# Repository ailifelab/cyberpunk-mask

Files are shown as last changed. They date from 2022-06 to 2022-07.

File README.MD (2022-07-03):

# Cyberpunk Mask    
一个基于ESP32的赛博朋克面具，通过右上角的菜单和按钮选择左下角屏幕显示的动画，以及控制跑马灯的灯效。

<hr>        

## 文件说明        
- CyberpunkMaskEsp32    
  基于Arduino的ESP-WAROOM-32代码，Boards Manager请安装esp32插件。

- MaskParts     
  solidworks模型文件
  - stl     
    STL格式的模型文件
<hr>

## 开发环境        
- Arduino IDE [1.8.19]      
- Board: esp32 [2.0.2]
  - DOIT ESP32 DEVKIT V1    
  - Upload speed: 921600 (Default)
  - Flash frequency: 80MHz (Default)
- Libraries:        
  - ESP32 Digital RGB LED Drivers [76863da42599f7b082821e4cee0ea00ba23b0918] | https://github.com/MartyMacGyver/ESP32-Digital-RGB-LED-Drivers | WS2812跑马灯带 (安装库的非本次使用的版本，已复制到本项目代码中)      
  - ESP8266 and ESP32 OLED driver for SSD1306 displays [4.3.0]| https://github.com/ThingPulse/esp8266-oled-ssd1306 | SSD1306 OLED I2C屏幕       
  - Time [1.6.1] | Arduino 时间库      
 
<hr>

## 电路图
本次使用的是Goouuu-ESP32，引脚定义如下，可以根据实际芯片的端口调整接线，具体请调整代码中的I/O定义。      
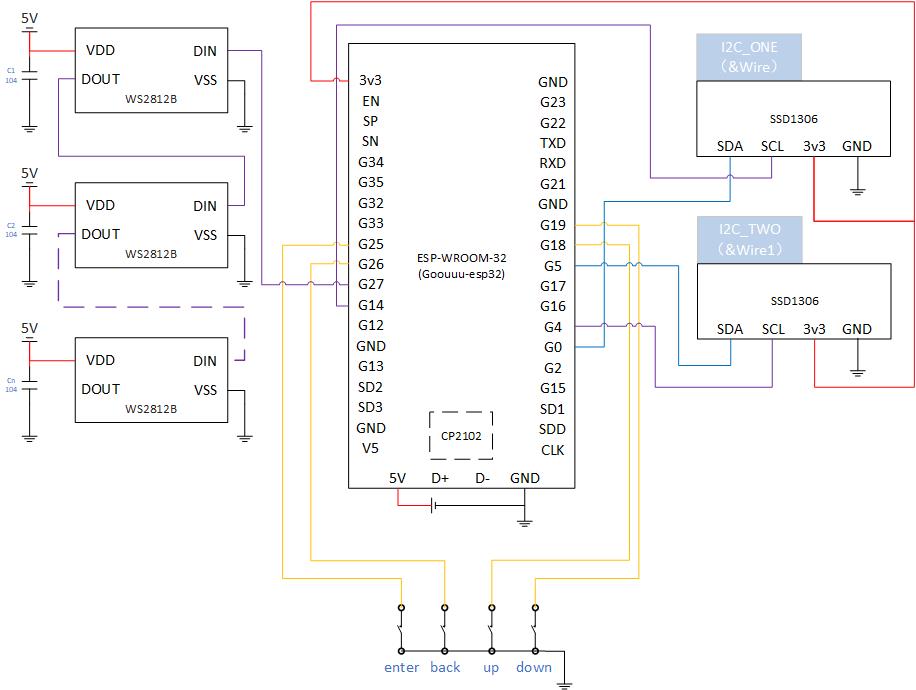
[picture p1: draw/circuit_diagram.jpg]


## 装配
### 3D打印的零件(TPU打印材料 ￥64/kg)        
- 菜单显示屏固定架(part_menu_frame)：      
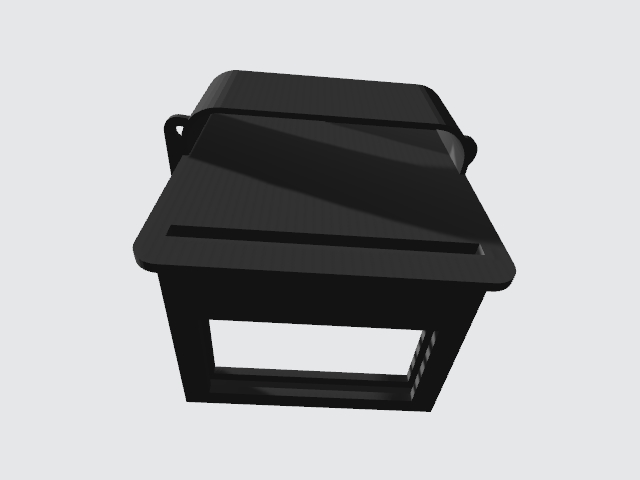
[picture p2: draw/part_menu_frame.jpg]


- 图形显示屏固定架(part_screen_frame)：      
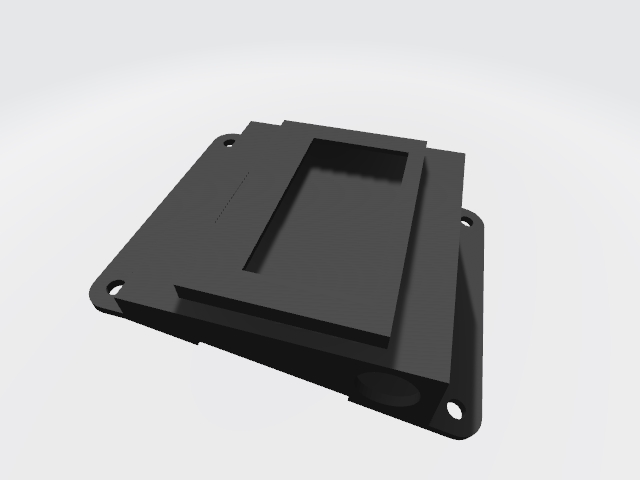
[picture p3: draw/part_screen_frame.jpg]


- 中间连接器(part_connector)：      
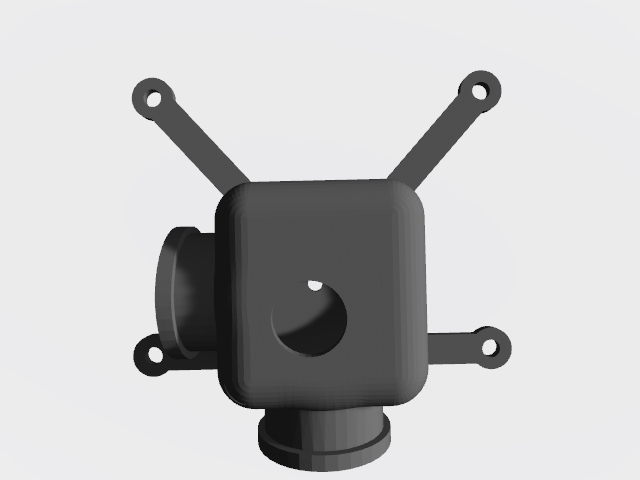
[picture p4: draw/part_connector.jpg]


- 主板固定架(part_board_cage)：      
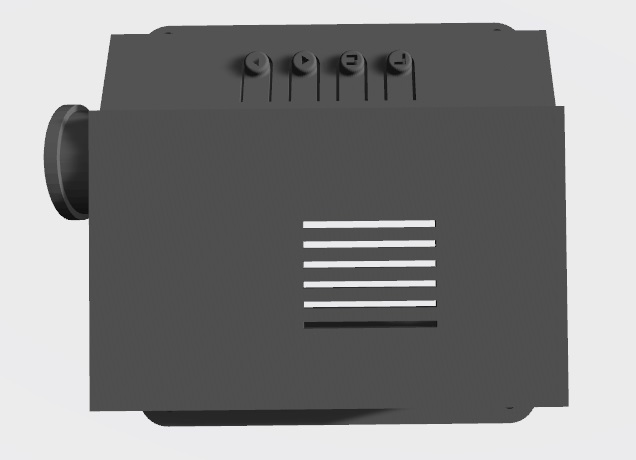
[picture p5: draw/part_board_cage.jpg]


### 购买的零件
- 面具（￥25）      
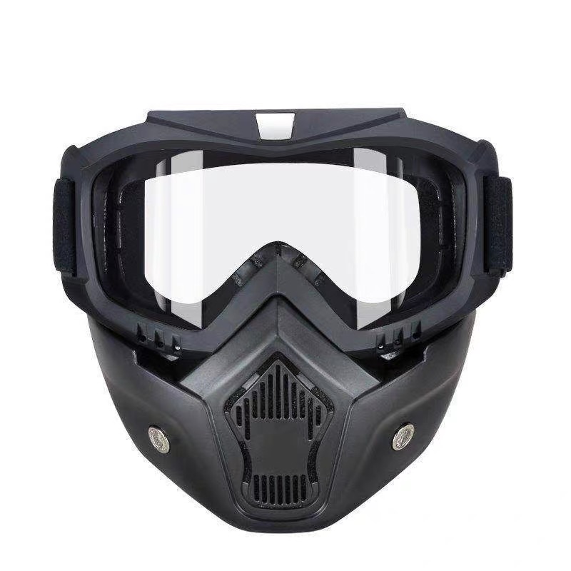
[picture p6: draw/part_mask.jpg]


- OLED透明显示屏1.51寸 128*64（SSD1306 ￥56）×2       
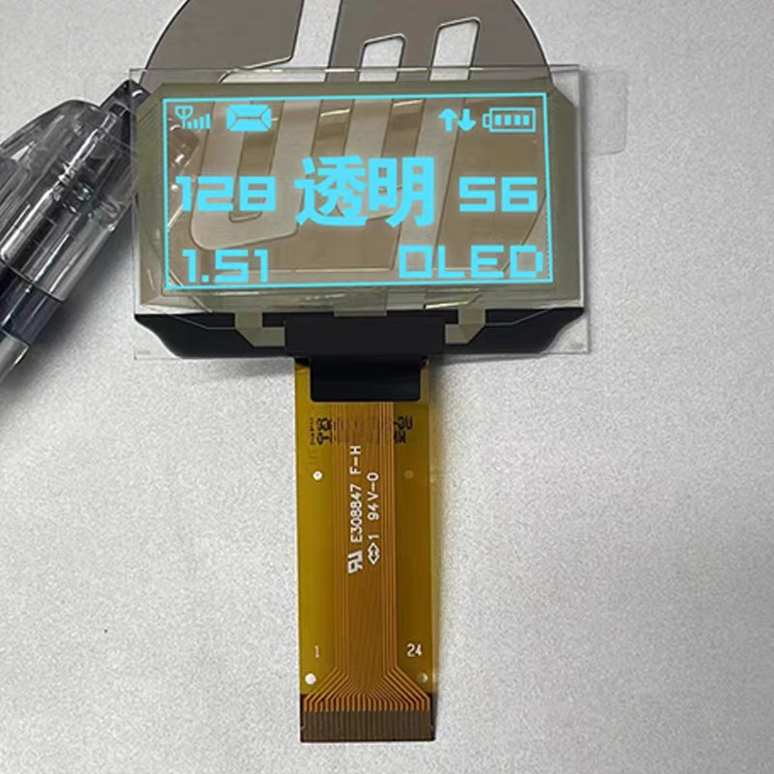
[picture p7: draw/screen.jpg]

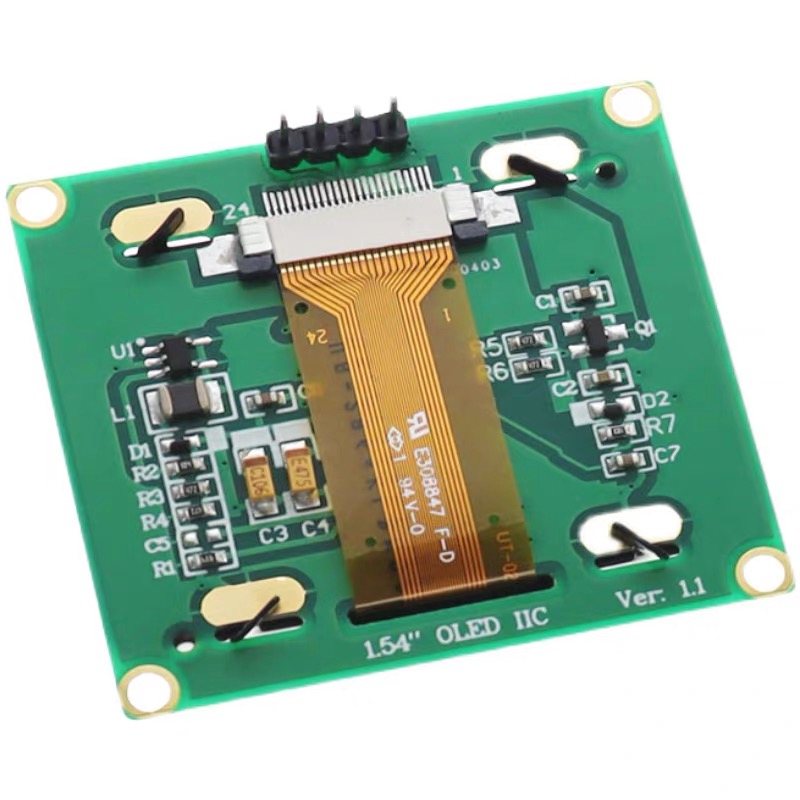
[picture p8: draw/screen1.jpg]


- WS2812B LED灯带 60灯（￥17/m）        
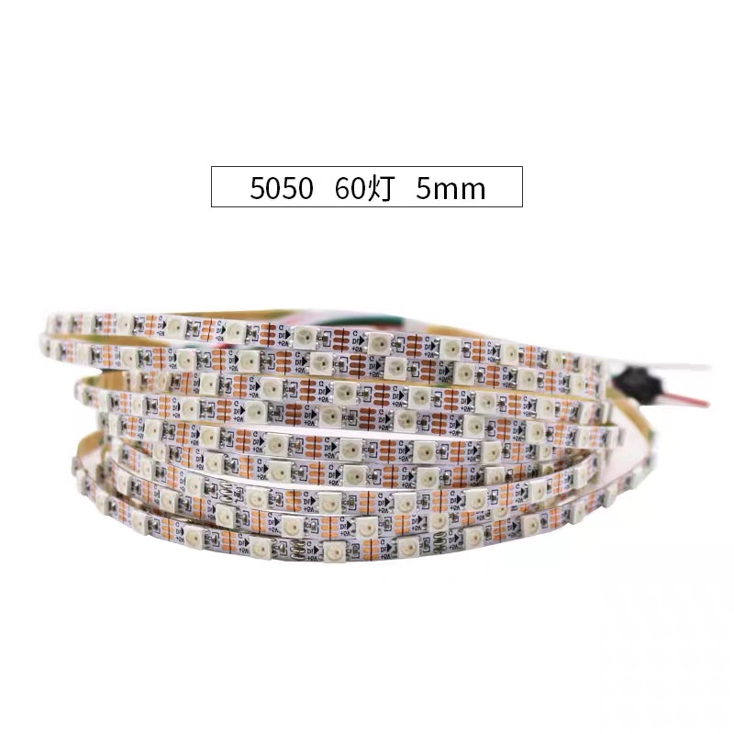
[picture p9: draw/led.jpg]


- ESP32 ESP-WROOM-32（Goouuu-ESP32 ￥21）     
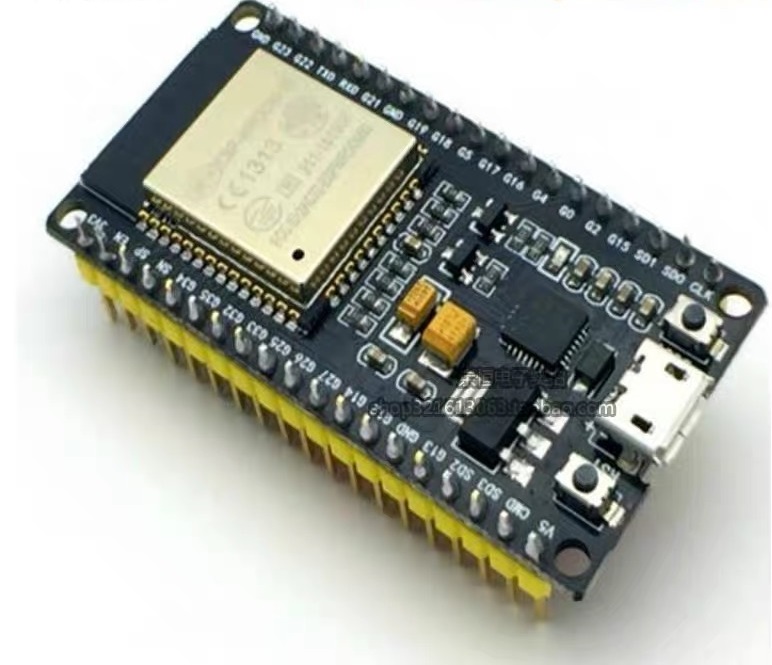
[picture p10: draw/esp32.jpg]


- PE波纹管（AD10:￥5/5m,AD21.2：￥5.8/5m）     
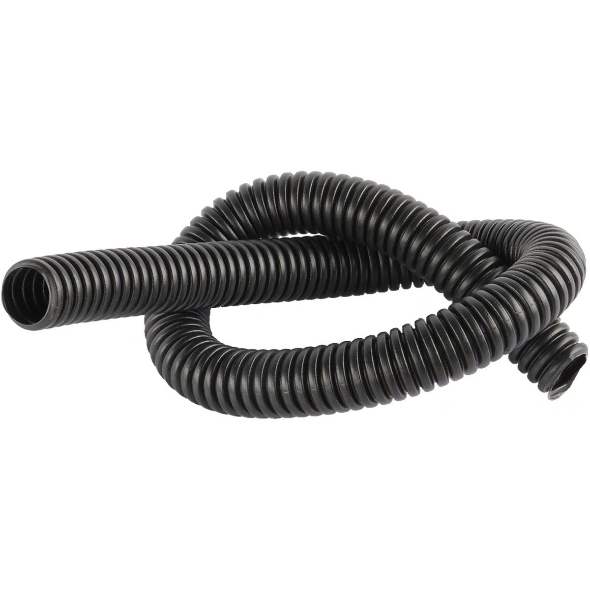
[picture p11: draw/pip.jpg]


- 灯带硅胶外壳（D13*13 ￥10/m）          
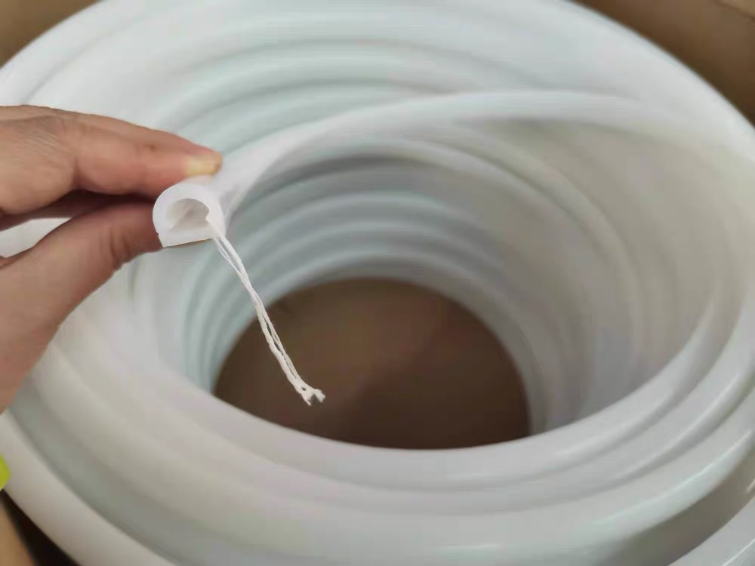
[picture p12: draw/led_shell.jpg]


- 导线若干

### 成品      
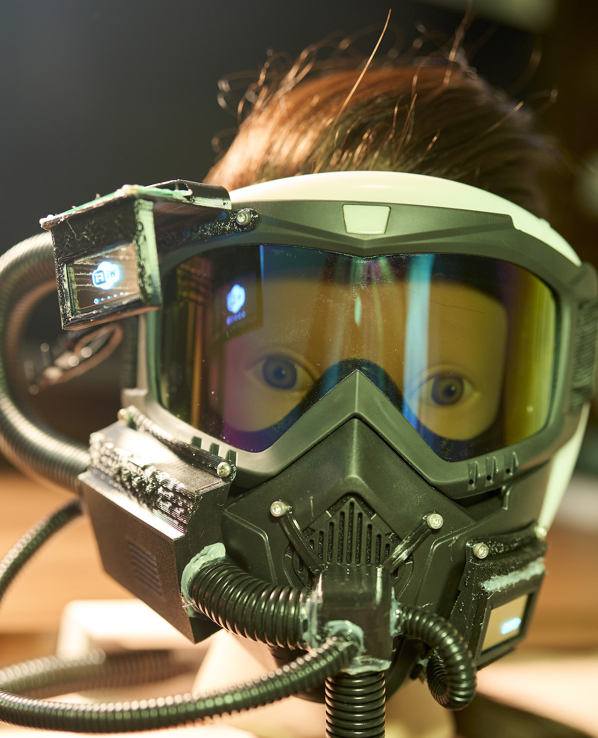
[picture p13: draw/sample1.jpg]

<hr>

## 效果
Play on youtube (https://www.youtube.com/embed/BOateCBAd_g)

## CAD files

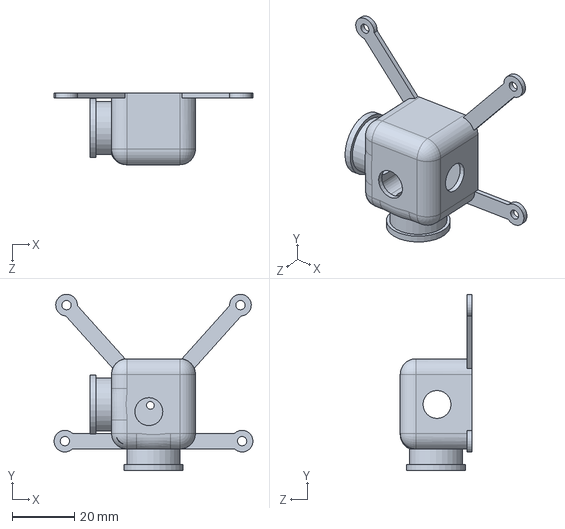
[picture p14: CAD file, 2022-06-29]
MaskParts/part_connector.SLDPRT
64.0 x 56.7 x 23.0 mm

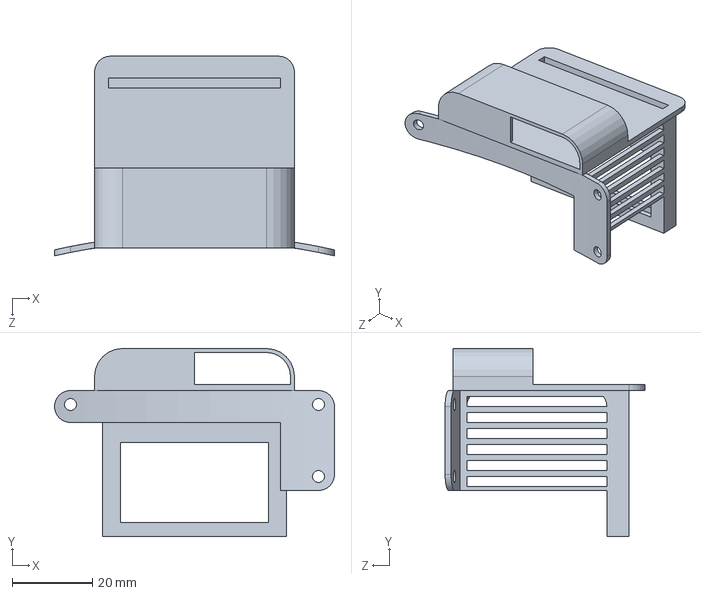
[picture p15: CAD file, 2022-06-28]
MaskParts/part_menu_frame.SLDPRT
70.0 x 47.0 x 49.9 mm

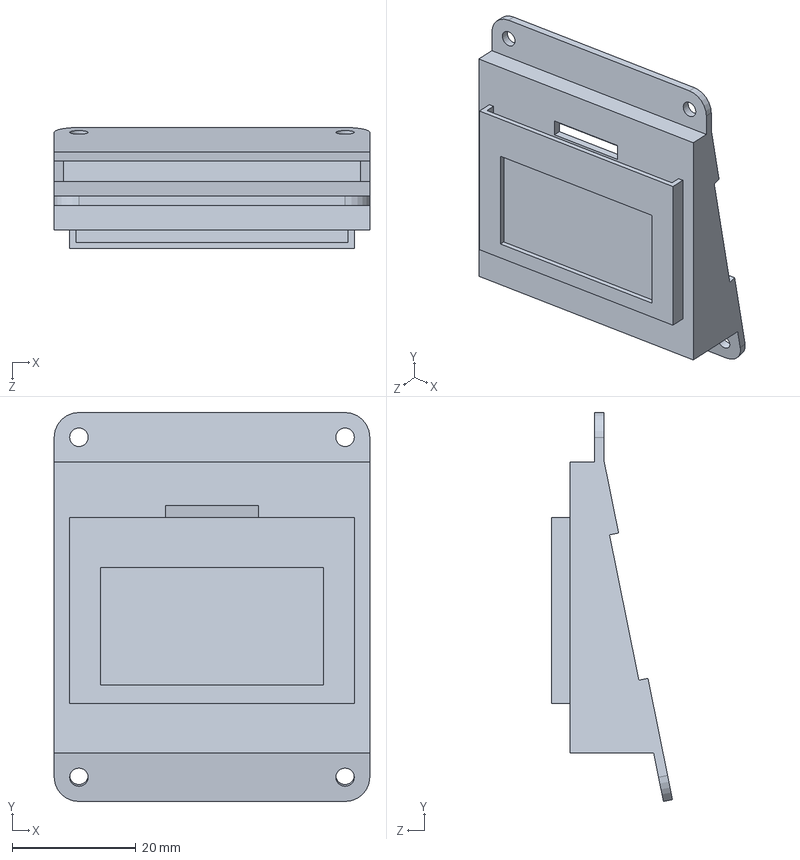
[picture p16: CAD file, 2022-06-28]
MaskParts/part_screen_frame.SLDPRT
51.0 x 62.8 x 19.6 mm

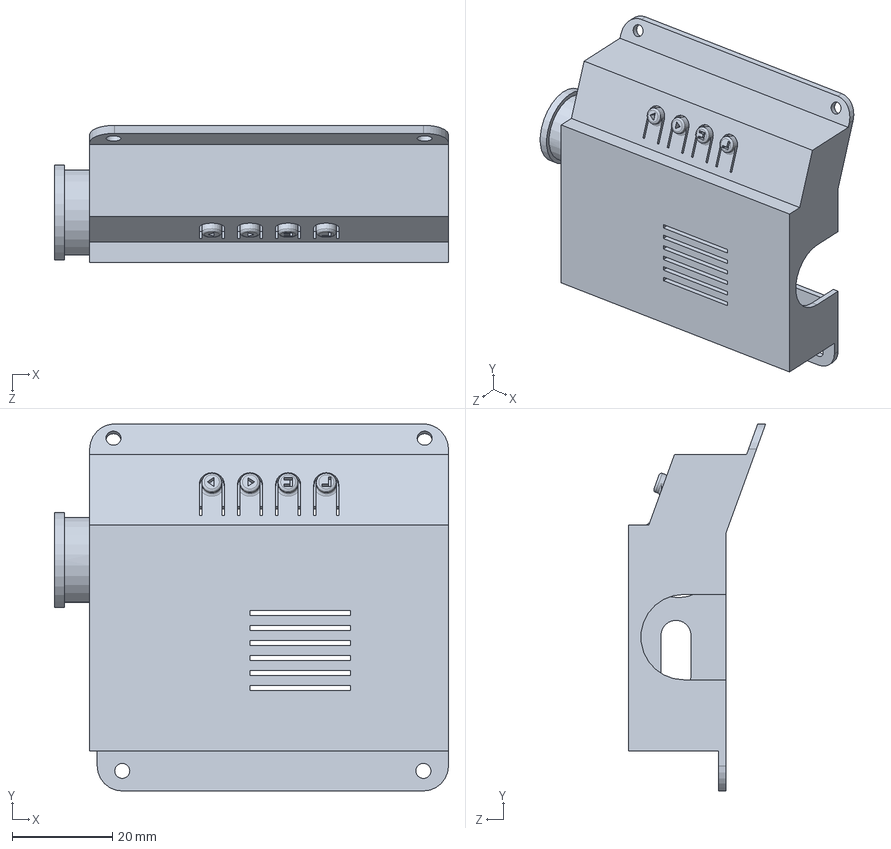
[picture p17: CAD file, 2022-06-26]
MaskParts/part_board_cage.SLDPRT
78.5 x 73.1 x 27.4 mm

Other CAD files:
MaskParts/stl/part_board_cage.STL
MaskParts/stl/part_connector.STL
MaskParts/stl/part_menu_frame.STL
MaskParts/stl/part_screen_frame.STL

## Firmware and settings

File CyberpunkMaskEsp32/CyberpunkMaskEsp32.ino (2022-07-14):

/**
   Cyberpunk Mask Diplay Controller
   使用ESP-WROOM-32主板
   External libraries:
     1.ESP32 Digital RGB LED Drivers | https://github.com/MartyMacGyver/ESP32-Digital-RGB-LED-Drivers | WS2812跑马灯带
     2.ESP8266 and ESP32 OLED driver for SSD1306 displays| https://github.com/ThingPulse/esp8266-oled-ssd1306 | SSD1306 OLED I2C屏幕
     3.Time | 时间库
*/
#include <Wire.h>  // Only needed for Arduino 1.6.5 and earlier
#include <TimeLib.h>
#include "SSD1306Wire.h"
#include "OLEDDisplayUi.h"
#include "esp32_digital_led_lib.h" //流水灯控制
#include "ControlUi.h"
#include "led_brand_effects.h"
//定义输出
#define LED_BAND_PIN 27
#define DISP_SDA_1 0
#define DISP_SCL_1 14
#define DISP_SDA_2 5
#define DISP_SCL_2 4
//定义按钮
#define BTN_UP 18
#define BTN_DOWN 19
#define BTN_ENTER 25
#define BTN_BACK 26
int preBtnStatUp = HIGH;
int preBtnStatDown = HIGH;
int preBtnStatEnter = HIGH;
int preBtnStatBack = HIGH;
#define LIGHT_NUM_METER 22

// Initialize the OLED display using Wire library
SSD1306Wire  display(0x3c, DISP_SDA_1 , DISP_SCL_1, GEOMETRY_128_64, I2C_ONE);
SSD1306Wire  display2(0x3c, DISP_SDA_2, DISP_SCL_2, GEOMETRY_128_64, I2C_TWO);
//display 用于菜单选择控制
OLEDDisplayUi ui ( &display );
ControlUi controlUi ( &ui, &display2 );

//for LED band
#define COUNT_OF(x) ((sizeof(x)/sizeof(0[x])) / ((size_t)(!(sizeof(x) % sizeof(0[x])))))
#pragma GCC diagnostic push
#pragma GCC diagnostic ignored "-Wmissing-field-initializers"  // It's noisy here with `-Wall`
strand_t strand = {.rmtChannel = 0, .gpioNum = LED_BAND_PIN, .ledType = LED_WS2812B_V3, .brightLimit = 30, .numPixels = LIGHT_NUM_METER};
strand_t * STRANDS [] = { &strand };
int STRANDCNT = COUNT_OF(STRANDS);
#pragma GCC diagnostic pop

LedBrandEffects * ledbrand;

/****绘制菜单****/
/**
   an over layer
*/
void msOverlay(OLEDDisplay *display, OLEDDisplayUiState* state) {
  display->setTextAlignment(TEXT_ALIGN_RIGHT);
  display->setFont(ArialMT_Plain_10);
  display->drawString(128, 0, String(millis()));
}

// Overlays are statically drawn on top of a frame eg. a clock
OverlayCallback overlays[] = { msOverlay };
int overlaysCount = 1;
/***绘制菜单 end****/

uint8_t menuNum = 0;
/**
   按钮控制
*/
void btnControl() {
  int btnStatUp = digitalRead(BTN_UP);
  int btnStatDown = digitalRead(BTN_DOWN);
  int btnStatEnter = digitalRead(BTN_ENTER);
  int btnStatBack = digitalRead(BTN_BACK);
  if ((btnStatUp != preBtnStatUp) && (btnStatUp == LOW)) {
    ui.previousFrame();
  }
  if ((btnStatDown != preBtnStatDown) && (btnStatDown == LOW)) {
    ui.nextFrame();
  }
  if ((btnStatEnter != preBtnStatEnter) && (btnStatEnter == LOW)) {
    Serial.println("button enter!");
    OLEDDisplayUiState* uiStat = ui.getUiState();
    uint8_t currentFrame = uiStat->currentFrame;
    if (menuNum == 0) {
      if (currentFrame == 0) {
        //main page do nothing
        menuNum = 0;
      } else if (currentFrame == 1) {
        //drawFlowLed
        controlUi.goFlowLedChoose();
        menuNum = 1;
      } else if (currentFrame == 2) {
        //drawOled
        controlUi.goDisplayChoose();
        menuNum = 2;
      } else if (currentFrame == 3) {
        //drawBle
        //        menuNum = 3;
      } else if (currentFrame == 4) {
        //drawWifi
        //        menuNum = 4;
      }
    } else if (menuNum == 1) {
      //choose led
      ledbrand->setEffNum(currentFrame);
    } else if (menuNum == 2) {
      //choose image show
      controlUi.setSecondImage(currentFrame);
    }
  }
  if ((btnStatBack != preBtnStatBack) && (btnStatBack == LOW)) {
    Serial.println("button back!");
    controlUi.goHome();
    if (menuNum == 1) {
      ui.switchToFrame(1);
    } else if (menuNum == 2) {
      ui.switchToFrame(2);
    } else if (menuNum == 3) {
      ui.switchToFrame(3);
    } else if (menuNum == 4) {
      ui.switchToFrame(4);
    }
    menuNum = 0;
  }
  preBtnStatUp = btnStatUp;
  preBtnStatDown = btnStatDown;
  preBtnStatEnter = btnStatEnter;
  preBtnStatBack = btnStatBack;
}

/**
   初始化
*/
void setup() {
  Serial.begin(115200);
  Serial.println("Initializing...");
  // Initialising the UI will init the display too.
  // The ESP is capable of rendering 60fps in 80Mhz mode
  // but that won't give you much time for anything else
  // run it in 160Mhz mode or just set it to 30 fps
  ui.setTargetFPS(60);
  ui.init();
  //  display.setTextAlignment(TEXT_ALIGN_CENTER);
  //  display.setFont(ArialMT_Plain_10);
  //  display.drawString(64, 18, "Initializing");
  //  display.drawProgressBar(4, 32, 120, 8, 10);
  digitalLeds_initDriver();
  gpioSetup(BTN_UP, INPUT_PULLUP, HIGH);
  gpioSetup(BTN_DOWN, INPUT_PULLUP, HIGH);
  gpioSetup(BTN_ENTER, INPUT_PULLUP, HIGH);
  gpioSetup(BTN_BACK, INPUT_PULLUP, HIGH);
  gpioSetup(strand.gpioNum, OUTPUT, LOW);
  int rc = digitalLeds_addStrands(STRANDS, STRANDCNT);
  //  if (rc) {
  //    Serial.print("Init rc = ");
  //    Serial.println(rc);
  //  }
  //  if (digitalLeds_initDriver()) {
  //    Serial.println("Init FAILURE: halting");
  //    while (true) {};
  //  }
  digitalLeds_resetPixels(STRANDS, STRANDCNT);
  ledbrand = new LedBrandEffects(&strand);
  //  display.drawProgressBar(4, 32, 120, 8, 30);

  display2.init();
  // This will make sure that multiple instances of a display driver
  // running on different ports will work together transparently
  display2.setI2cAutoInit(true);
  //  display2.flipScreenVertically();
  //  display.drawProgressBar(4, 32, 120, 8, 60);

  unsigned long secsSinceStart = millis();
  // Unix time starts on Jan 1 1970. In seconds, that's 2208988800:
  const unsigned long seventyYears = 2208988800UL;
  // subtract seventy years:
  unsigned long epoch = secsSinceStart - seventyYears * SECS_PER_HOUR;
  setTime(epoch);

  //  display.drawProgressBar(4, 32, 120, 8, 100);
  controlUi.goHome();
  // Add overlays
  //  ui.setOverlays(overlays, overlaysCount);
  Serial.println("Initialized.");
}

void loop() {
  int remainingTimeBudget = ui.update();
  long startTime = millis();

  controlUi.renderSecondScreen();

  // randomStrands(STRANDS, STRANDCNT, 200, 10000);
  //  rainbows(STRANDS, STRANDCNT, 1, 10);
  // simpleStepper(STRANDS, STRANDCNT, 0, 0);
  ledbrand->renderLed();
  btnControl();

  long endTime = millis() - startTime;
  //等待ui处理完成
  if (remainingTimeBudget > endTime) {
    delay(remainingTimeBudget - endTime);
  }
}

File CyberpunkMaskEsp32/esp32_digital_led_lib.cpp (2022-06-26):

/* 
 * Library for driving digital RGB(W) LEDs using the ESP32's RMT peripheral
 *
 * Modifications Copyright (c) 2017-2019 Martin F. Falatic
 * 
 * Portions modified using FastLED's ClocklessController as a reference
 *   Copyright (c) 2018 Samuel Z. Guyer
 *   Copyright (c) 2017 Thomas Basler
 *
 * Based on public domain code created 19 Nov 2016 by Chris Osborn <fozztexx@fozztexx.com>
 * http://insentricity.com
 *
 */

/*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
 * THE SOFTWARE IS PROVIDED "AS IS", WITHOUT WARRANTY OF ANY KIND, EXPRESS OR
 * IMPLIED, INCLUDING BUT NOT LIMITED TO THE WARRANTIES OF MERCHANTABILITY,
 * FITNESS FOR A PARTICULAR PURPOSE AND NONINFRINGEMENT. IN NO EVENT SHALL THE
 * AUTHORS OR COPYRIGHT HOLDERS BE LIABLE FOR ANY CLAIM, DAMAGES OR OTHER
 * LIABILITY, WHETHER IN AN ACTION OF CONTRACT, TORT OR OTHERWISE, ARISING FROM,
 * OUT OF OR IN CONNECTION WITH THE SOFTWARE OR THE USE OR OTHER DEALINGS IN
 * THE SOFTWARE.
 */

#include "esp32_digital_led_lib.h"


#ifdef __cplusplus
extern "C" {
#endif

#if defined(ARDUINO)
  #include "esp32-hal.h"
  #include "esp_intr_alloc.h"
  #include "driver/gpio.h"
  #include "driver/rmt.h"
  #include "driver/periph_ctrl.h"
  #include "freertos/semphr.h"
  #include "soc/rmt_struct.h"
#elif defined(ESP_PLATFORM)
  #include <esp_intr.h>
  #include <driver/gpio.h>
  #include <driver/rmt.h>
  #include <freertos/FreeRTOS.h>
  #include <freertos/semphr.h>
  #include <soc/dport_reg.h>
  #include <soc/gpio_sig_map.h>
  #include <soc/rmt_struct.h>
  #include <stdio.h>
  #include <string.h>  // memset, memcpy, etc. live here!
#endif

#ifdef __cplusplus
}
#endif

#define COUNT_OF(x) ((sizeof(x)/sizeof(0[x])) / ((size_t)(!(sizeof(x) % sizeof(0[x])))))

#if DEBUG_ESP32_DIGITAL_LED_LIB
extern char * digitalLeds_debugBuffer;
extern int digitalLeds_debugBufferSz;
#endif

static DRAM_ATTR const uint16_t MAX_PULSES = 32;  // A channel has a 64 "pulse" buffer - we use half per pass
static DRAM_ATTR const uint16_t DIVIDER    =  4;  // 8 still seems to work, but timings become marginal
static DRAM_ATTR const double   RMT_DURATION_NS = 12.5;  // Minimum time of a single RMT duration based on clock ns


// Considering the RMT_INT_RAW_REG (raw int status) and RMT_INT_ST_REG (masked int status) registers (each 32-bit):
//   Where op = {raw, st, ena, clr} and n = {0..7}
//   Every three bits = RMT.int_<op>.ch<n>_tx_end, RMT.int_<op>.ch<n>_rx_end, RMT.int_<op>.ch<n>_err
//   The final 8 bits are RMT.int_<op>.ch<n>_tx_thr_event

// LUT for mapping bits in RMT.int_<op>.ch<n>_tx_thr_event
static DRAM_ATTR const uint32_t tx_thr_event_offsets [] = {
  static_cast<uint32_t>(1) << (24 + 0),
  static_cast<uint32_t>(1) << (24 + 1),
  static_cast<uint32_t>(1) << (24 + 2),
  static_cast<uint32_t>(1) << (24 + 3),
  static_cast<uint32_t>(1) << (24 + 4),
  static_cast<uint32_t>(1) << (24 + 5),
  static_cast<uint32_t>(1) << (24 + 6),
  static_cast<uint32_t>(1) << (24 + 7),
};

// LUT for mapping bits in RMT.int_<op>.ch<n>_tx_end
static DRAM_ATTR const uint32_t tx_end_offsets [] = {
  static_cast<uint32_t>(1) << (0 + 0) * 3,
  static_cast<uint32_t>(1) << (0 + 1) * 3,
  static_cast<uint32_t>(1) << (0 + 2) * 3,
  static_cast<uint32_t>(1) << (0 + 3) * 3,
  static_cast<uint32_t>(1) << (0 + 4) * 3,
  static_cast<uint32_t>(1) << (0 + 5) * 3,
  static_cast<uint32_t>(1) << (0 + 6) * 3,
  static_cast<uint32_t>(1) << (0 + 7) * 3,
};

typedef union {
  struct {
    uint32_t duration0:15;
    uint32_t level0:1;
    uint32_t duration1:15;
    uint32_t level1:1;
  };
  uint32_t val;
} rmtPulsePair;

typedef struct {
  uint8_t * buf_data;
  uint16_t buf_pos, buf_len, buf_half, buf_isDirty;
  rmtPulsePair pulsePairMap[2];
  bool isProcessing;
} digitalLeds_stateData;

double randDouble()
{
  return double(esp_random()>>16) / (UINT16_MAX + 1);
}

pixelColor_t adjustByUniformFactor(pixelColor_t * color, double adjFactor) {
  color->r = uint8_t(color->r * (1.0 - adjFactor));
  color->g = uint8_t(color->g * (1.0 - adjFactor));
  color->b = uint8_t(color->b * (1.0 - adjFactor));
  color->w = uint8_t(color->w * (1.0 - adjFactor));
  return *color;
}


const static int MAX_RMT_CHANNELS = 8;
static strand_t * strandDataPtrs[MAX_RMT_CHANNELS] = {nullptr};  // Indexed by RMT channel

// Forward declarations of local functions
static void copyHalfBlockToRmt(strand_t * pStrand);
static void rmtInterruptHandler(void *arg);


static xSemaphoreHandle gRmtSem = nullptr;
static intr_handle_t gRmtIntrHandle = nullptr;

static int gToProcess = 0;


#if defined(ARDUINO) && ARDUINO >= 100
  void espPinMode(int pinNum, int pinDir) {
    // Enable GPIO32 or 33 as output. Device-dependent
    // (only works if these aren't used for external XTAL).
    // https://esp32.com/viewtopic.php?t=9151#p38282
    if (pinNum == 32 || pinNum == 33) {
      uint64_t gpioBitMask = (pinNum == 32) ? 1ULL<<GPIO_NUM_32 : 1ULL<<GPIO_NUM_33;
      gpio_mode_t gpioMode = (pinDir == OUTPUT) ? GPIO_MODE_OUTPUT : GPIO_MODE_INPUT;
      gpio_config_t io_conf;
      io_conf.intr_type = GPIO_INTR_DISABLE;
      io_conf.mode = gpioMode;
      io_conf.pin_bit_mask = gpioBitMask;
      io_conf.pull_down_en = GPIO_PULLDOWN_DISABLE;
      io_conf.pull_up_en = GPIO_PULLUP_DISABLE;
      gpio_config(&io_conf);
    }
    else {
      pinMode(pinNum, pinDir);
    }
  }
#endif


void gpioSetup(int gpioNum, int gpioMode, int gpioVal) {
  #if defined(ARDUINO) && ARDUINO >= 100
    espPinMode(gpioNum, gpioMode);
    digitalWrite (gpioNum, gpioVal);
  #elif defined(ESP_PLATFORM)
    gpio_num_t gpioNumNative = static_cast<gpio_num_t>(gpioNum);
    gpio_mode_t gpioModeNative = static_cast<gpio_mode_t>(gpioMode);
    gpio_pad_select_gpio(gpioNumNative);
    gpio_set_direction(gpioNumNative, gpioModeNative);
    gpio_set_level(gpioNumNative, gpioVal);
  #endif
}


int digitalLeds_initDriver()
{
  #if DEBUG_ESP32_DIGITAL_LED_LIB
    snprintf(digitalLeds_debugBuffer, digitalLeds_debugBufferSz, "digitalLeds_initDriver\n");
  #endif

  esp_err_t rc = ESP_OK;

  if (gRmtIntrHandle == nullptr) {  // Only on first run
    // Sem is created here
    gRmtSem = xSemaphoreCreateBinary();
    xSemaphoreGive(gRmtSem);
    rc = esp_intr_alloc(ETS_RMT_INTR_SOURCE, 0, rmtInterruptHandler, nullptr, &gRmtIntrHandle);
  }

  return rc;  
}
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

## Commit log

2022-06-23 '初始化控制代码'
2022-06-23 fix 调整显示屏2的i2c通道，确保两个屏幕都能显示内容
2022-06-26 新增部分模型
    [part_board_cage.SLDPRT, part_board_cage.STL, part_connector.SLDPRT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]
2022-06-26 调整菜单操作
2022-06-28 修改模型
    [part_connector.SLDPRT, part_connector.STL, part_menu_frame.SLDPRT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]
2022-06-29 修改模型孔大小
    [part_connector.SLDPRT, part_connector.STL]
2022-07-03 更新说明文件
2022-07-04 添加显示选项
2022-07-04 更新显示图形
2022-07-05 '更新动画'
2022-07-14 初始化led灯带效果
